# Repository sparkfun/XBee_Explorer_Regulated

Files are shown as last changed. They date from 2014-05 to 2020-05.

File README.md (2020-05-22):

XBee Explorer Regulated
=======================
Xbee Explorer Regulated (https://www.sparkfun.com/products/11373)

*[XBee Explorer Regulated (WRL-11373)](https://www.sparkfun.com/products/11373)*
 
 This Explorer regulates 5V serial signals to 3.3V to enable communication with the XBee modules.
 This model works with all XBee modules, including Series 1 and 2, standard and Pro versions. 
 
Repository Contents
-------------------

* **/Hardware** - All Eagle design files (.brd, .sch)

License Information
-------------------
The hardware is released under [Creative Commons ShareAlike 4.0 International](https://creativecommons.org/licenses/by-sa/4.0/).
The code is beerware; if you see me (or any other SparkFun employee) at the local, and you've found our code helpful, please buy us a round!

Distributed as-is; no warranty is given.

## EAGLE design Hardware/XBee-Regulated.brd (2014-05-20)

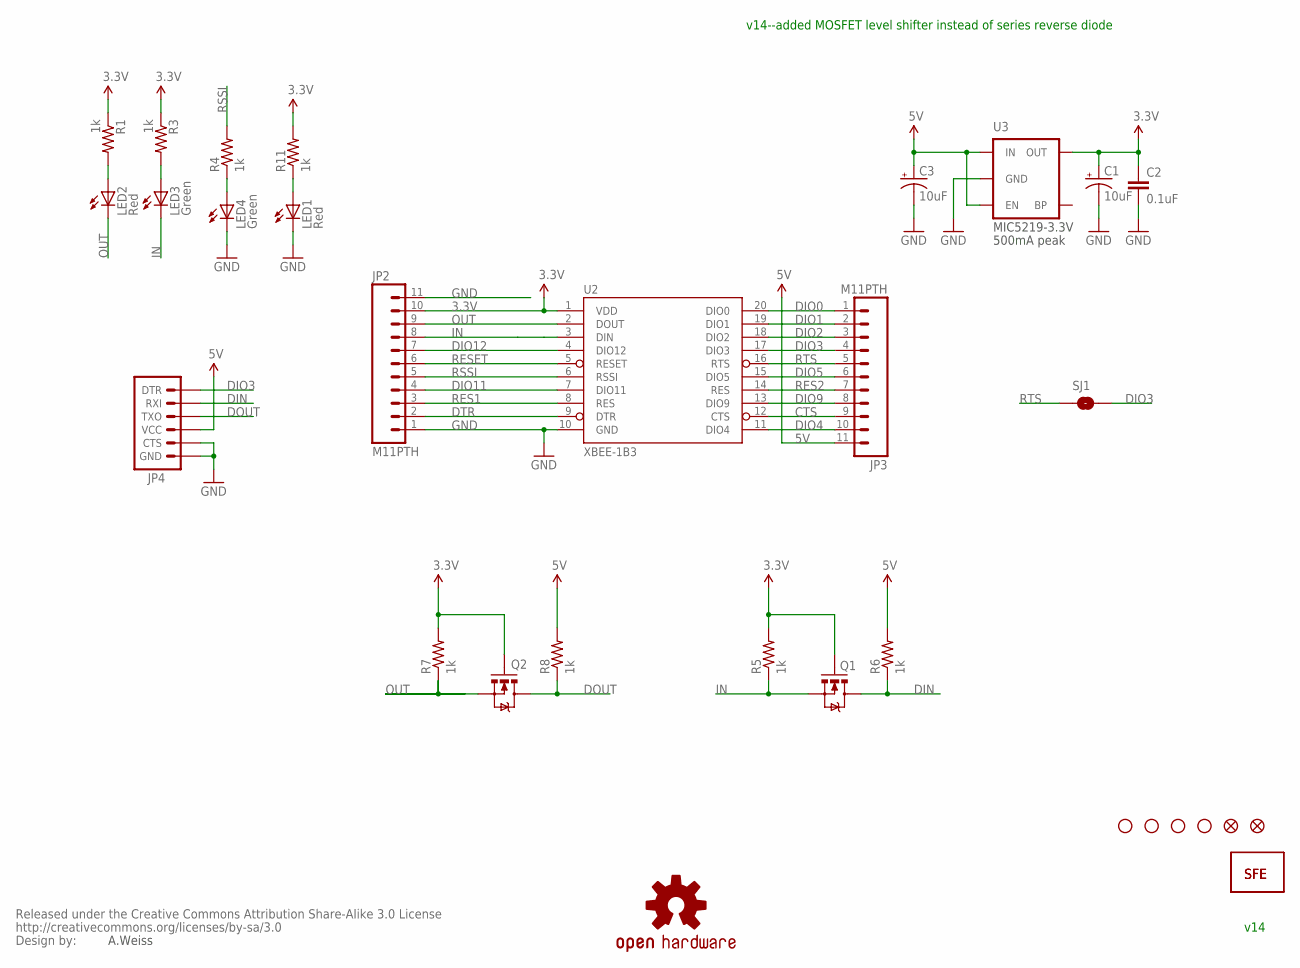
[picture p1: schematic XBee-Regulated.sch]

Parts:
C1, C3: 10uF; EIA3216
C2: 0.1uF; 0402-CAP
JP2, JP3: M11PTH; 1X11
JP4: ARDUINO_SERIAL_PROGRAMPTH; 1X06
LED1, LED2: Red; LED-0603
LED3, LED4: Green; LED-0603
Q1, Q2: MOSFET-NCHANNELSMD; SOT23-3
R1, R3, R4, R5, R6, R7, R8, R11: 1k; 0402-RES
SJ1: SOLDERJUMPERNO; SJ_2S-NO
U2: XBEE-1B3; XBEE-SMD
U3: V_REG_LDOSMD; SOT23-5
U$1: LOGO-SFESK; SFE-LOGO-FLAME
U$3: OSHW-LOGOS; OSHW-LOGO-S
U$4: LOGO-SFENEW; SFE-NEW-WEBLOGO
U$5, U$9, U$10, U$11: STAND-OFF
U$7, U$16: FIDUCIAL1X2; FIDUCIAL-1X2
U$8: CREATIVE_COMMONS

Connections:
3.3V: C1.A (+), C2.1, JP2.10, Q1.1 (G), Q2.1 (G), R1.1, R3.1, R5.2, R7.2, R11.2, U2.1 (VDD), U3.5 (OUT)
5V: C3.A (+), JP3.11, JP4.4 (VCC), R6.2, R8.2, U3.1 (IN), U3.3 (EN)
CTS: JP3.9, U2.12 (CTS)
DIN: JP4.2 (RXI), Q1.3 (D), R6.1
DIO0: JP3.1, U2.20 (DIO0)
DIO1: JP3.2, U2.19 (DIO1)
DIO2: JP3.3, U2.18 (DIO2)
DIO3: JP3.4, JP4.1 (DTR), SJ1.2, U2.17 (DIO3)
DIO4: JP3.10, U2.11 (DIO4)
DIO5: JP3.6, U2.15 (DIO5)
DIO9: JP3.8, U2.13 (DIO9)
DIO11: JP2.4, U2.7 (DIO11)
DIO12: JP2.7, U2.4 (DIO12)
DOUT: JP4.3 (TXO), Q2.3 (D), R8.1
DTR: JP2.2, U2.9 (DTR)
GND: C1.C (-), C2.2, C3.C (-), JP2.1, JP2.11, JP4.5 (CTS), JP4.6 (GND), LED1.C, LED4.C, U2.10 (GND), U3.2 (GND)
IN: JP2.8, LED3.C, Q1.2 (S), R5.1, U2.3 (DIN)
unnamed: LED2.A, R1.2
unnamed: LED4.A, R4.1
unnamed: LED3.A, R3.2
unnamed: LED1.A, R11.1
OUT: JP2.9, LED2.C, Q2.2 (S), R7.1, U2.2 (DOUT)
RES1: JP2.3, U2.8 (RES)
RES2: JP3.7, U2.14 (RES)
RESET: JP2.6, U2.5 (RESET)
RSSI: JP2.5, R4.2, U2.6 (RSSI)
RTS: JP3.5, SJ1.1, U2.16 (RTS)

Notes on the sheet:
A.Weiss
v14--added MOSFET level shifter instead of series reverse diode
MIC5219-3.3V
500mA peak
v14

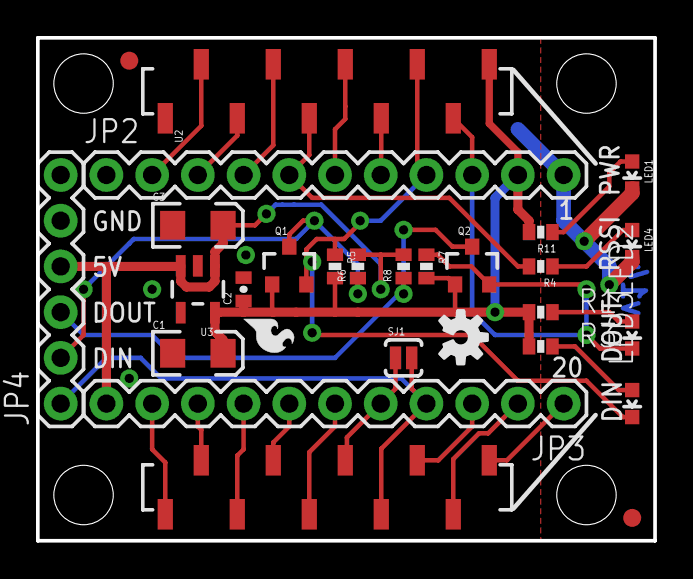
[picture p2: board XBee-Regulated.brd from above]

Board: 2 copper layers, 34.3 x 27.9 mm, 33 parts (1 on the bottom side), 27 nets.

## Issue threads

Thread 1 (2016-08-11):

6-pin header connections (JP4)

daescalona, 2016-08-11:
Hello,

I have been playing recently with Sparkfun boards and XBee devices, specifically I have used these two boards:
- SparkFun XBee Explorer Regulated Board: https://www.sparkfun.com/products/11373
- SparkFun FTDI Basic Breakout - 3.3V: https://www.sparkfun.com/products/9873

So, the first thought I had as a customer is that the 6-pin header connector of each board was compatible, and I could attach one board to the other one using a 90º pin header connector. I was wrong, only GND and VCC lines are compatible. The Rx and Tx lines are crossed, which is the main issue, but also the DTR and CTS lines are wrong. So I have several questions:
- Is there any reason the 6 pin header (JP4) is designed that way? (maybe compatibility with any other board or something?) Could it be updated/improved so that it is 1:1 compatible with the FTDI boards?
- Could Rx and Tx lines be interchanged in the JP4 header connector?
- Why is CTS line of JP4 connected to ground? It should be connected to pin 12 of XBee (JP3 9).
- Why is DTR line of JP4 connected to XBee DIO3 (JP3 4)? That line should be connected to pin 9 of XBee (JP2 2).

The DTR and CTS lines issue is specially worrying. It avoids users to use Hardware Flow control in the connected XBee device as the lines are no properly connected to the XBee socket.

I am attaching an image displaying what must be done currently to attach both boards:

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

Kind regards.

bboyho, 2020-05-22:
Hi,

Sorry for the delay in reply. I noticed your question when browsing a few issues. If you are still wondering, the serial interface (JP4) on the XBee Explorer was designed to directly mate with Arduino development boards. It was not designed to mate directly with an FTDI  since the board was intended to be the "FTDI-side" of the standard "Arduino <=> FTDI" setup. The CTS and DTR pins were arranged in this fashion for simple serial interface and [wireless bootloading](https://www.sparkfun.com/tutorials/122).

As a result, there are no plans to update the board to be 1:1 compatible with an FTDI.

Closed 2020-05-22.

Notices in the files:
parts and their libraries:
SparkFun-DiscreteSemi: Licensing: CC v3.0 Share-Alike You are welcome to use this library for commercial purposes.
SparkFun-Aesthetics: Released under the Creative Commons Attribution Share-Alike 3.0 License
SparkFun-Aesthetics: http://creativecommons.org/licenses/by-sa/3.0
